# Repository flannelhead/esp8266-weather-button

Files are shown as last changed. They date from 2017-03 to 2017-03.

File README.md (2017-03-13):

# ESP8266 weather button

A simple weather display that is based on ESP8266. It connects to a WiFi network, fetches weather data from a weather API, stores it in the RTC memory and goes to deep sleep. After a fixed interval it wakes up and fetches the data again. If the user presses the reset button, the 128x64 OLED display is lighted and the stored weather forecast is displayed.

## Weather data source

The weather data is pulled from the [OpenWeatherMap API](https://openweathermap.org/api), which is available under [CC-BY-SA 4.0](http://creativecommons.org/licenses/by-sa/4.0/). Terms of use are listed [here](https://openweathermap.org/terms).

## Libraries

The [u8g2](https://github.com/olikraus/u8g2) graphics library by olikraus is included in this repo and is licensed under the BSD 2-clause license. The library also contains fonts which are licensed under various licenses. See the respective [LICENSE file](u8g2/LICENSE) for details.

The makefile has been adapted from Spritetm's [esphttpd](https://github.com/Spritetm/esphttpd) repo. In addition, there is a custom linker script `eagle.app.v6.custom.ld` which is the `eagle.app.v6.ld` from the Espressif SDK with one change: `.text` and `.literal` sections are located in `irom0` section by default, so there is no need to prefix functions with `ICACHE_FLASH_ATTR`. This also allows using the u8g2 code as-is.

[jsmn-stream](https://github.com/flannelhead/jsmn-stream) is a fork/rewrite of [jsmn](https://github.com/zserge/jsmn) by Serge Zaitsev (MIT license). It is used for incremental JSON parsing.

[esphttpclient](https://github.com/Caerbannog/esphttpclient) is used for requesting weather data over HTTP.

The NTP client is from Richard Burton's [esp8266 repository](https://github.com/raburton/esp8266), licensed under the MIT license.

## License

The code is released under GPLv3. See the LICENSE file for details.

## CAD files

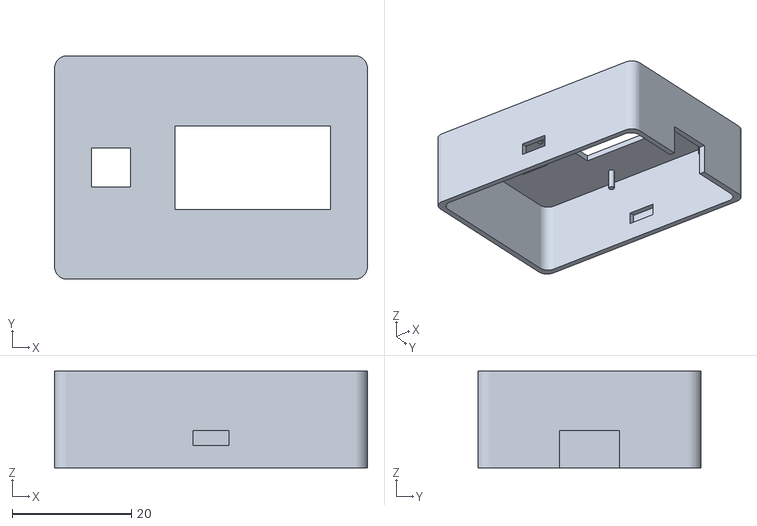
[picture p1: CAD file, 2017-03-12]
design/box_top.stl
52.4 x 37.4 x 16.2

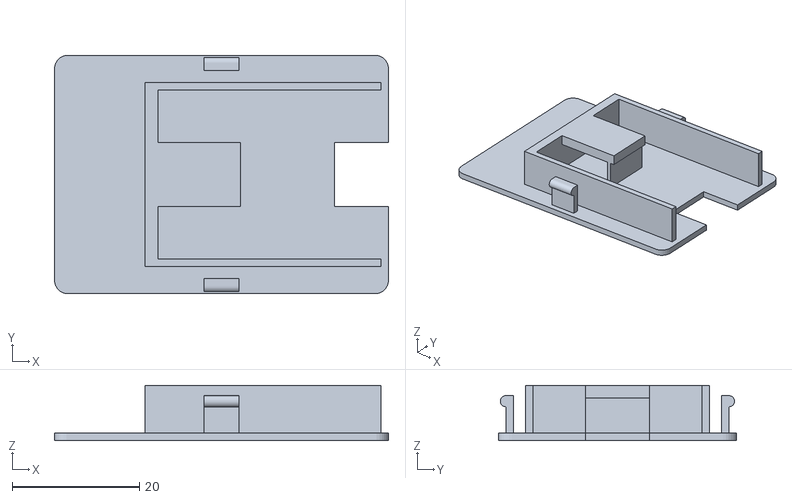
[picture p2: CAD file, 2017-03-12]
design/box_bottom_lid.stl
52.4 x 37.4 x 8.70

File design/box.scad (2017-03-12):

shell_t = 1.2;
inner_w = 50;
inner_h = 35;
inner_l = 15;
corner_r = 2;

lcd_opening_w = 26;
lcd_opening_h = 14;
lcd_up_offset = 6.5;
lcd_opening_x_margin = 5;

lcd_pegs_span_x = 23.5;
lcd_pegs_span_y = 24;
lcd_pegs_d = 1.2;
lcd_pegs_h = 4 + shell_t;
lcd_pegs_y_shift = 1.5;

button_d = 6.5;
button_x_margin = 5;

snap_slit_width = 6;
snap_slit_height = 2.5;
snap_slit_z = 5;

usb_slit_w = 10;
usb_slit_h = 8;
usb_slit_depth = 8;

cage_inner_wx = 35;
cage_inner_wy = 26.5;
cage_h = 7.5;
cage_t = 1.2;
cage_claw_wy = 10;
cage_claw_wx = 15;
cage_claw_t = 2;

tolerance = 0.5;

$fs = 0.01;

module box(width, height, length) {
     translate([inner_w / 2, inner_h / 2, 0]) linear_extrude(length) minkowski() {
         circle(r=corner_r);
         square([width - 2*corner_r, height - 2*corner_r], center = true);
     }
}

module box_shell() {
    difference() {
        translate([-shell_t, -shell_t, 0])
        resize([inner_w + 2*shell_t, inner_h + 2*shell_t, 0]) 
            box(inner_w, inner_h, inner_l + shell_t);
        translate([0, 0, -shell_t]) box(inner_w, inner_h, inner_l + shell_t);
    }
}

module lcd_pegs() {
    translate([-lcd_pegs_span_x / 2, -lcd_pegs_span_y / 2])
        cylinder(d=lcd_pegs_d, h=lcd_pegs_h);
    translate([lcd_pegs_span_x / 2, -lcd_pegs_span_y / 2])
        cylinder(d=lcd_pegs_d, h=lcd_pegs_h);
    translate([-lcd_pegs_span_x / 2, lcd_pegs_span_y / 2])
        cylinder(d=lcd_pegs_d, h=lcd_pegs_h);
    translate([lcd_pegs_span_x / 2, lcd_pegs_span_y / 2])
        cylinder(d=lcd_pegs_d, h=lcd_pegs_h);
}

module side_slits() {
    translate([inner_w / 2, 0, snap_slit_z])
        cube([snap_slit_width, 2*shell_t, snap_slit_height], center=true);
    translate([inner_w / 2, inner_h, snap_slit_z])
        cube([snap_slit_width, 2*shell_t, snap_slit_height], center=true);
}

module usb_slit() {
    translate([inner_w - usb_slit_depth / 2 + shell_t, inner_h/2, usb_slit_h / 2 - shell_t - 1])
        cube([usb_slit_depth + 1, usb_slit_w, usb_slit_h + 1], center = true);
}

module box_main() {
    difference() {
        box_shell();
        
        // Screen opening
        translate([inner_w - lcd_opening_w/2 - lcd_opening_x_margin,
            inner_h / 2, inner_l + 0.5*shell_t])
        cube([lcd_opening_w, lcd_opening_h, 2*shell_t], center=true);
        
        // Button opening
        translate([button_x_margin, (inner_h - button_d) / 2, inner_l - 0.5*shell_t])
            cube([button_d, button_d, 2*shell_t]);
        
        side_slits();        
        usb_slit();
    }
    
    translate([inner_w - lcd_opening_w/2 - lcd_opening_x_margin,
        inner_h / 2 + lcd_pegs_y_shift,
        inner_l - lcd_pegs_h + shell_t]) lcd_pegs();
}

module snap_tab() {
    tab_width = snap_slit_width - tolerance;
    snap_tab_r = 0.7 * snap_slit_height / 2;
    translate([(inner_w - tab_width) / 2, 0, 0]) {
        cube([tab_width, shell_t, snap_slit_z + snap_tab_r]);
        translate([0, 0, snap_slit_z])
            rotate([0, 90, 0]) cylinder(h=tab_width, r=snap_tab_r);
    }    
}

module board_cage() {
    translate([cage_claw_t, 0, 0]) {
        cube([cage_inner_wx, cage_t, cage_h]);
        translate([0, cage_inner_wy + cage_t, 0]) cube([cage_inner_wx, cage_t, cage_h]);
    }
    cube([cage_claw_t, cage_inner_wy + 2*cage_t, cage_h]);
    translate([0, cage_t + (cage_inner_wy - cage_claw_wy) / 2, cage_h - cage_claw_t])
        cube([cage_claw_wx, cage_claw_wy, cage_claw_t]);
    translate([cage_claw_wx - 1.6, cage_t + (cage_inner_wy - cage_claw_wy) / 2, 0])
        cube([0.8, cage_claw_wy, cage_h - cage_claw_t]);
}

module bottom_lid() {
    difference() {
        union() {
            translate([-shell_t, -shell_t, -shell_t])
                resize([inner_w + 2*shell_t, inner_h + 2*shell_t, 0]) 
                box(inner_w, inner_h, shell_t);
            snap_tab();
            translate([0, inner_h, 0]) mirror([0, 1, 0]) snap_tab();
            
            translate([inner_w - (cage_inner_wx + cage_claw_t),
                (inner_h - (cage_inner_wy + 2*cage_t)) / 2, 0]) board_cage();
        }
        usb_slit();
    }
}

box_main();
//bottom_lid();

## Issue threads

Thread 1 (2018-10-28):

Interested in use u8g2lib with brzoi2c on esp8266 but compiling over Arduino IDE

jirmjos, 2018-10-28:
Is any way to use your adapted library u8g2 with brzoi2c but to install and compile over arduino IDE patform?

Thank you so much,

flannelhead, 2018-10-29:
I think it's possible. There are some function calls and libraries specific to the ESP8266 non-OS SDK by Espressif (such as the `esphttpclient` lib) but there are equivalents within the ESP8266 Arduino environment.

However, there are also weather station codes natively made for the Arduino SDK, which might get you started better. For instance, you could have a look at the awesome [esp8266-weather-station](https://github.com/ThingPulse/esp8266-weather-station) project.

jirmjos, 2018-10-30:
Thanks for your quick reply!
Excuse my ignorance and ask questions that are probably obvious and somewhat stupid.
My quest is about integrate much faster i2c brzolib from Pasko (https://github.com/pasko-zh/brzo_i2c) on u8g2 library like you seems are do it in this project.
I´m on electronics and not a coder so my programing skills are very limitated, and in this moment I can only manage propperly in Arduino IDE compiler and in PlatformIO environment.
So I cannot understand how you had create your project here  (your programming environment) and how you compile and obtain finally the .bin file, and and even less how you build compiled your library u8g2 with brzoi2c integrated...
So any help on how I can have a u8g2 graphics library integrating brzoi2c "but ready for compile on Arduino IDE" is my goal and will be awesome if I can achieve.
Best regards.

flannelhead, 2018-10-30:
Hi,

Now I realize you are looking for just the integration between `u8g2` and `brzo_i2c`. I read your first message a bit too quickly, sorry about that.

`u8g2` is just a (almost) hardware-neutral library. Therefore, to integrate with physical hardware on a specific platform, a hardware abstraction layer (HAL) is required. For this, I've written a small (probably incomplete) HAL which uses `brzo_i2c` on the ESP8266 to communicate with the display. You can find the code [here in this repo](https://github.com/flannelhead/esp8266-weather-button/blob/master/lib/u8g2_esp8266_hal.c#L154). The link points directly to the I2C part of the HAL. I believe that part is almost directly applicable within the Arduino environment. There are also the GPIO manipulation, delay and SPI implementations. The SPI communication is not needed in case you use I2C for communication, but you would just have to port the GPIO and delay part [here](https://github.com/flannelhead/esp8266-weather-button/blob/master/lib/u8g2_esp8266_hal.c#L17) to the equivalent Arduino calls.

When initializing the `u8g2` instance, the hardware access implementations are selected [like this](https://github.com/flannelhead/esp8266-weather-button/blob/master/user/user_main.c#L219).

Hope this helps! Please don't hesitate to ask further questions if you need more info :)

jirmjos, 2018-10-31:
Hi Sakari.

Wooow wooow woooow !!!
Far above my current skills, to create a working library myself, but thank you very much for all your information. Surely in the next few days I'm trying to understand everything you say and I hope (of course, with a little (a lot) help) I hope I can do something else to at least start.

I'm totally amateur on programing and do something right with coding will be a hard work for me, so achieve make a c++ library for arduino will be like a dream for me in that moment...but sure I'm trying and time will tell.

A bounch of questions are  now in my mind, but first before "bombing" someone with thousand of questions better I try to understand and learn almost most basic.

Thank you so much

Jose,

jirmjos, 2018-12-03:
Hi again Sakari.
Well I have a "bittersweet" because have been successful on compiling at Arduino IDE an attempt to include brzo_i2c with your esp8266 hal, but I have not managed to work the oled display ssd1327.
I have made two attempts through the direct use of u8g2 (as I believe you use the library in your module for your oled 1306) and also adapting the complete library (using u8g2lib) orginal of olikraus.
In both cases I have managed to compile in Arduino IDE (version 1.8.7) with ESP8266 core (last stable version 2.4.2), but the OLED display does not change when I try to send any text to it.
Obviously using the u8g2lib constructor provided by the library (both software based U8G2_SSD1327_EA_W128128_F_SW_I2C u8g2 (U8G2_R0, / * reset = * / U8X8_PIN_NONE) and hardware version U8G2_SSD1327_EA_W128128_F_HW_I2C u8g2 (U8G2_R0, / * reset = * / U8X8_PIN_NONE)) both work.
Observing I think that what happens (a simple visual speculation) is that the display is not even initialized (I think that brzo_i2c does not achieve communication with the OLED), but as I have (I do not know) how to debug the i2c bus, for me it is impossible to know what is happening.
By the way, my OLED uses the address i2c 0x3c, so I think it is well configured, but I have doubts about it if I have allowed it to be encoded in any of the parameters of any of the libraries without having managed to know where, what would be the explanation to not even initialize the display.
I would appreciate it if you could give me a hand and try to see if I have a problem in the integration of the brzo_i2c libraries or it is a problem with your hal for esp8266 and the way in which I have linked it to u8g2 and brzo_i2c.
Any help on your part I think you could get it to succeed and it would be really important for me (and others) to be able to use this small and cheap display.

You can download my modified librarys from my github https://github.com/jirmjos/SSD1327_u8g2_Brzo_i2c_ESP8266_Hal

Regards
Thank you Sakari.

flannelhead, 2018-12-04:
Hi @jirmjos,

I think I'll have to try it out myself with the SSD1306 I have lying around somewhere. Please allow me some time though, since I am unfortunately a bit occupied before Christmas. At least I could try to get something together during the holidays.

Best,
Sakari

jirmjos, 2018-12-05:
Of course the important things are first, so do not worry at all about this. When you have availability and some free time let me know and we put again to this work, meanwhile I will check again everything I did and also I´m thinking about doing tests but with others type of displays since I have a couple more oled display liying around, one SSD1106 (1.3 inches) and I think I remember that I have some 0.96 inches that carries the SSD1306.
And finally, if you have some interested in having a 1.5 inch ssd1327 for do test or any what you need, please don´t hesitate to let me know and I will look how to send it to you.

Regards,
Jose

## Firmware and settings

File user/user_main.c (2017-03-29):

/*
ESP8266 weather display firmware
Copyright (C) 2017 Sakari Kapanen

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
You should have received a copy of the GNU General Public License
along with this program.  If not, see <http://www.gnu.org/licenses/>.
*/

#include <osapi.h>
#include <ets_sys.h>
#include <user_interface.h>
#include <espmissingincludes.h>
#include <driver/uart.h>

#include "u8g2.h"
#include "u8g2_esp8266_hal.h"

#include "ntp.h"
#include "httpclient.h"
#include "wifi_station.h"
#include "owmap_parser.h"

#include "util.h"
#include "credentials.h"
#include "my_config.h"

// All below are milliseconds
#define CONNECTION_TIMEOUT 10000
#define DATA_FETCH_TIMEOUT 10000
#define SCREEN_TIMEOUT 20000
#define DATA_FETCH_INTERVAL (5*60000)

#define FORECAST_MAX_COUNT 8

#define MAGIC_NUM 0x55aaaa55

os_timer_t timeout_timer;

u8g2_t u8g2;
weather_parser_t wparser;
bool idle_fetch;

void sleep_timeout(uint32_t timeout);

void oled_draw_forecast(int x, int y, const weather_t *forecast,
    bool draw_weekday) {
    int dx;

    u8g2_SetFontPosTop(&u8g2);

    struct tm *dt = gmtime(&forecast->time);
    char buf[32];
    if (draw_weekday) {
        os_sprintf(buf, "%s %02d", WEEKDAYS[dt->tm_wday], dt->tm_hour);
    } else {
        os_sprintf(buf, "%02d", dt->tm_hour);
    }
    dx = (32 - u8g2_GetUTF8Width(&u8g2, buf)) / 2;
    u8g2_DrawUTF8(&u8g2, x + dx, y, buf);

    const uint8_t *bitmap = get_weather_icon_bitmap(forecast->icon);
    if (bitmap != NULL) {
        u8g2_DrawXBMP(&u8g2, x, y + 14, 32, 32, bitmap);
    }

    os_sprintf(buf, "%d°C", forecast->temp);
    dx = (32 - u8g2_GetUTF8Width(&u8g2, buf)) / 2;
    u8g2_DrawUTF8(&u8g2, x + dx, y + 52, buf);
}

void oled_draw_forecasts(const weather_t *forecasts, int n_forecasts) {
    u8g2_ClearBuffer(&u8g2);

    int j, c;
    weather_t my_forecasts[3];
    for (j = 0, c = 0; j < n_forecasts && c < 3; ++j) {
        struct tm *dt = gmtime(&forecasts[j].time);
        if (dt->tm_hour <= 18 && dt->tm_hour >= 9) {
            my_forecasts[c] = forecasts[j];
            c += 1;
        }
    }
    if (c < 3) return;

    int prev_wday = 7;
    for (int i = 0; i < 3; ++i) {
        struct tm *dt = gmtime(&my_forecasts[i].time);
        oled_draw_forecast(2 + i*46, 0, &my_forecasts[i], dt->tm_wday != prev_wday);
        prev_wday = dt->tm_wday;
    }

    u8g2_SendBuffer(&u8g2);
}

void oled_init(void) {
    u8g2_SetPowerSave(&u8g2, 0); // wake up display
    u8g2_SetFont(&u8g2, u8g2_font_profont12_tf);
    u8g2_ClearDisplay(&u8g2);
}

void forecast_display() {
    uint32_t n_forecasts = 0;
    if (system_rtc_mem_read(65, &n_forecasts, 4) && n_forecasts != 0) {
        os_printf("Found %u forecasts\n", n_forecasts);
        wparser.forecast_count = n_forecasts;
        system_rtc_mem_read(67, wparser.forecasts,
            n_forecasts * sizeof(weather_t));
    }
    oled_init();
    oled_draw_forecasts(wparser.forecasts, n_forecasts);
    sleep_timeout(SCREEN_TIMEOUT);
}

void go_to_sleep(uint32_t sleep_timeout) {
    os_printf("Going to sleep, timeout = %u\n", sleep_timeout);
    u8g2_SetPowerSave(&u8g2, 1); // put display to sleep
    system_deep_sleep(1000 * sleep_timeout);
}

void sleep_timer_cb(void *arg) {
    uint32_t *timeout = (uint32_t *)arg;
    go_to_sleep(*timeout);
}

void http_get_callback(char * response_body, int http_status,
    char * response_headers, int body_size) {
    static int current_status = 0;
    if (response_headers != NULL) {
        current_status = http_status;
        weather_parser_init(&wparser);
    }
    if (current_status == 200 && response_body != NULL) {
        char ch;
        while ((ch = *(response_body++)) != '\0') {
            weather_stream_parse(&wparser, ch);
        }
    }

    if (http_status == HTTP_STATUS_DISCONNECT) {
        os_timer_disarm(&timeout_timer);
        uint32_t data_length = wparser.forecast_count;
        uint32_t flag = 0;
        system_rtc_mem_write(64, &flag, 4);
        system_rtc_mem_write(65, &data_length, 4);
        system_rtc_mem_write(67, wparser.forecasts, data_length * sizeof(weather_t));
        flag = MAGIC_NUM;
        system_rtc_mem_write(64, &flag, 4);
        os_printf("Fetched %u forecasts\n", data_length);
        if (!idle_fetch) {
            forecast_display();
        } else {
            go_to_sleep(DATA_FETCH_INTERVAL);
        }
    }
}

char owmap_query[128];
void do_owmap_query(void) {
    os_sprintf(owmap_query,
        "http://api.openweathermap.org/data/2.5/forecast?id=%s&appid=%s&units=metric",
        OWMAP_CITY_ID, OWMAP_API_KEY);

    http_get(owmap_query, "", http_get_callback);  // Example domain for testing for now - this sends chunked responses
}

void ntp_cb(time_t timestamp, struct tm *dt) {
    apply_tz(dt, TIMEZONE_OFFSET);
    os_printf("Date %d.%d, time %d.%d\n",
        dt->tm_mday, dt->tm_mon + 1, dt->tm_hour, dt->tm_min);
    do_owmap_query();
}

void ntp_dns_cb(uint8_t *addr) {
    if (addr == NULL) {
        os_printf("Error resolving NTP server address\n");
        return;
    }

    ntp_get_time(addr, ntp_cb);
}

uint32_t data_fetch_interval = DATA_FETCH_INTERVAL;
void sleep_timeout(uint32_t timeout) {
    os_timer_disarm(&timeout_timer);
    os_timer_setfn(&timeout_timer, (os_timer_func_t *)sleep_timer_cb,
        &data_fetch_interval);
    os_timer_arm(&timeout_timer, timeout, false);
}

void wifi_connect_cb(bool connected) {
    if (connected) {
        sleep_timeout(DATA_FETCH_TIMEOUT);
        //dns_resolve("time.nist.gov", ntp_dns_cb);
        do_owmap_query();
    } else {
        go_to_sleep(DATA_FETCH_INTERVAL);
    }
}

void fetch_weather_data(void) {
    wifi_station_init(WIFI_SSID, WIFI_PWD, wifi_connect_cb, CONNECTION_TIMEOUT);
}

void user_init(void) {
    uint16_t adc = system_adc_read();
    system_update_cpu_freq(80);
    uart_init(BIT_RATE_115200, BIT_RATE_115200);

    u8g2_Setup_ssd1306_i2c_128x64_noname_f(&u8g2, U8G2_R0,
        u8x8_byte_brzo_sw_i2c,
        //u8x8_byte_sw_i2c,
        u8x8_gpio_and_delay_esp8266);  // init u8g2 structure
    u8g2_InitDisplay(&u8g2); // send init sequence to the display, display is in sleep mode after this

    idle_fetch = false;
    if (adc > 850) {
        // We've woken up to update the data
        idle_fetch = true;
        os_printf("Doing idle fetch...\n");
        fetch_weather_data();
    } else {
        uint32_t flag = 0;
        if (system_rtc_mem_read(64, &flag, 4) && flag == MAGIC_NUM) {
            os_printf("Displaying data directly from RTC...\n");
            forecast_display();
        } else {
            os_printf("Going to display data, fetching first...\n");
            fetch_weather_data();
        }
    }
}

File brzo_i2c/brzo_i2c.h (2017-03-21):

/*
brzo_i2c.h -- A fast i2c master for the esp8266 written in assembly language

Copyright (c) 2016 Pascal Kurtansky (pascal at kurtansky dot ch).
All rights reserved.

This file is part of the library brzo_i2c.

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
*/

#ifndef _BRZO_I2C_h
#define _BRZO_I2C_h

#ifdef ARDUINO
#include "Arduino.h"
#else
#include <c_types.h>

// SDA on GPIO12, SCL on GPIO13
#define BRZO_I2C_SDA_MUX PERIPHS_IO_MUX_GPIO4_U
#define BRZO_I2C_SCL_MUX PERIPHS_IO_MUX_GPIO5_U
#define BRZO_I2C_SDA_GPIO 4
#define BRZO_I2C_SCL_GPIO 5
#define BRZO_I2C_SDA_FUNC FUNC_GPIO4
#define BRZO_I2C_SCL_FUNC FUNC_GPIO5

#endif

#ifdef __cplusplus
extern "C" {
#endif

#ifdef ARDUINO
void brzo_i2c_setup(uint8_t sda, uint8_t scl, uint32_t clock_stretch_time_out_usec);
#else
void brzo_i2c_setup(uint32_t clock_stretch_time_out_usec);
#endif

void brzo_i2c_start_transaction(uint8_t slave_address, uint16_t SCL_frequency_KHz);
void brzo_i2c_write(uint8_t *data, uint32_t no_of_bytes, bool repeated_start);
void brzo_i2c_read(uint8_t *data, uint32_t nr_of_bytes, bool repeated_start);
void brzo_i2c_ACK_polling(uint16_t ACK_polling_time_out_usec);
uint8_t brzo_i2c_end_transaction();

#ifdef __cplusplus
}
#endif

#endif

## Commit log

2017-03-04 Add working ESP8266 SPI HAL
2017-03-05 Optimize SPI transfer
2017-03-11 Add design files
    [box.scad, box_bottom_lid.stl, box_top.stl]
2017-03-12 Updates to design
    [box.scad, box_bottom_lid.stl, box_top.stl]
2017-03-21 brzo_i2c and I2C HAL for U8G2

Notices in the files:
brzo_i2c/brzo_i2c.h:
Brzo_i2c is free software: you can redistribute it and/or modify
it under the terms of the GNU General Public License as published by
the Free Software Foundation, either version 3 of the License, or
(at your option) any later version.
